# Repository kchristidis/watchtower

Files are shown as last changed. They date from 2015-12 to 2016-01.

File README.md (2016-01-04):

# Watchtower

NC State ECE Senior Design Project, Fall 2015

## Description

Monitor the state of a building (temperature, luminosity, number of people) with easy-to-deploy Pi-based sensor boxes and an intuitive Web interface.

Allow others to access a sensor box you own using the dashboard.

Use the REST API to programmatically export sensor data, and build applications on top of **Watchtower**.

[Video presentation](https://www.youtube.com/watch?v=rJIvThQTJWE) of the project on Design Day: 24m01s to 25m02s

## Contents

  - Source code for the Web interface
  - Schematics for the Pi PCB
  - Scripts for the Pi
  - Screenshots
  - Documentation

## Credits

Coded by:
  - Andrew Kofink <ajkofink@ncsu.edu>
  - Spencer Hitchins <jshitchi@ncsu.edu>
  - Scott Whalen <swwhalen@ncsu.edu>

Mentored by:
  - Kostas Christidis <kchrist@ncsu.edu>
  - Michael Devetsikiotis <mdevets@ncsu.edu>

Sponsored by: 
  - IBM

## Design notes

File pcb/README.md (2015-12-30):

  - `sensor_pcb.brd` is the board file for EagleCAD for the PCB in our project that connects to the Raspberry Pi
  - `sensor_pcb.sch` is the schematic file for EagleCAD for the PCB in our project that connects to the Raspberry Pi
  - `gerber-files` contains all the files needed when sending the PCB to a manufacturer

When soldering the sensors on there is a label next to each set of wholes on the top side saying which sensor goes where, and on the under side shows a `V` for where the positive voltage pin should go. For a more simple explanation of how to orient the sensors, when looking at the side with the name labels and with the double row of pin wholes on the top you want each sensor to be mostly to the right of the pin wholes that go with that sensor.

Scott Whalen
swwhalen@ncsu.edu

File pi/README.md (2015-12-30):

# scm-scripts

## Author:
Spencer Hitchins (jshitchi@ncsu.edu)

## Python Version: 
python-2.7.9

## System Dependencies:
Adafruit BMP085 Python Library
pip
postgresql
python-opencv
RPi.GPIO
virtualenv

## Getting Started:

#### Enter scm-scripts directory:
cd scm-scripts

#### Create and activate virtualenv:
virtualenv venv
source venv/bin/activate

#### Install dependencies:
pip install -r requirements.pip

#### Create secrets file:
touch secrets.py

#### Copy example config file to config file location (descriptions of how to change this file are included in the example file):
cp conf/sensors.ini.example conf/sensors.ini

#### Run people counting script in background:
python people_counter.py &

#### Run data capture script
python capture_data.py

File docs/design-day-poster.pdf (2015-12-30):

## Complete System Overview

## Counting People with a Camera

# Team 4: Tracking and Predicting the State of a Building

A

Custom PCB

Temperature
Sensor

Luminosity
Sensor

Barometric
Pressure
Sensor

Number of
People

# Team Members: Scott Whalen, Andrew Kofink, Spencer Hitchins Sponsors & Mentors: IBM, Kostas Christidis, Prof. Michael Devetsikiotis

Web Application Logic
IBM’s Bluemix with 512MB RAM, 1 running process

Web Interface

Buildings and Sensor Modules Raspberry

Pi

Raspberry
Pi
Web Access

Database
PostgreSQL on IBM’s Compose with 1GB storage, auto-scalable IO

Sensor readings sent at
configurable frequency (30 min.)

Left
Quad

Right
Quad

## Requirements

- Web application
- Collects data from sensor modules (Raspberry Pi)
- Displays historical data
- Aesthetically pleasing
- Prediction for variables
- Tracks variables
- Light
- Temperature
- Barometric Pressure
- Number of People (Motion)

## Problem Statement

To have an inexpensive electronic device that can track the state of a building. The data will be shown in a web app, and will also be used for predicting future states of a building.

## Conclusions

- OpenCV can effectively be used to count objects passing through the frame of a Pi camera.
- Typical infrared emitter/detector diodes have a severely limited range of operation (5-25cm).
- The luminosity sensor was significantly affected by the clear plastic case. Holes were drilled in the case to accommodate this issue.

The camera
module shown
above is used in
conjunction with
custom image
processing
software to count
the number of
people travelling
in a given
direction.

## Web Application

- assigns each sensor module a unique serial number, which is displayed on a sticker on the module
- graphs historical data as well as future predictions up to 1 week into the future
- enforces user-defined access privileges for sensor data

## Sensor Module

- Raspberry Pi B+ with Custom PCB
- The device boots when the user connects power via a provided AC to 5V DC converter
- Data is sent as soon as the device boots
- Data is sent from all four sensors once every 30 minutes

## Sensors

Barometric pressure | Temperature

Luminosity

These three sensors communicate via I

2C

Number of
people

## Testing and Demo

- We installed 3 sensor modules in Troxler lab for 2 weeks prior to design day for historical data.

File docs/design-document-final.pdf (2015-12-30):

# Team 4

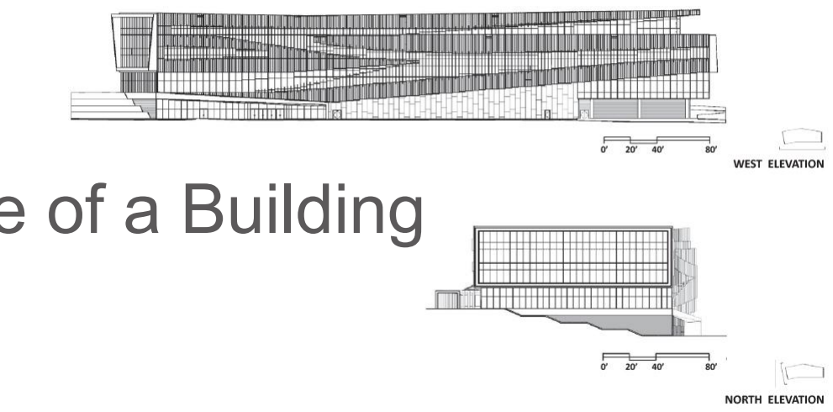
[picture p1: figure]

# Tracking and Predicting the State of a Building

## Faculty Mentors Kostas Christidis Bobby Compton

Spencer Hitchins | Sensor Control Module Manager, UI Design Specialist, Sponsor Contact
Andrew Kofink | Web Application Manager, Software Specialist, Documentation Specialist
Scott Whalen | PCB Manager, Project Leader, Hardware Specialist

# Introduction

# - IBM is sponsoring this internet of things (IoT) project - Track multiple sensor variables about a building - Display historic data and make forecasts via a web app - Motivations: - Inexpensive electronics - Many devices in the IoT - Need a common data interface

# Project Requirements

# - IoT devices push data to DB - web application displays data - system is easy to use - IBM technology is showcased - multiple sensor data per module

# Change Summary

# - no more detailed prediction algorithms - web app overhaul - switched database - shifted focus from extensibility to ease of use - sound sensor dropped - enclosure added

# Project Architecture

# Raspberry Pi

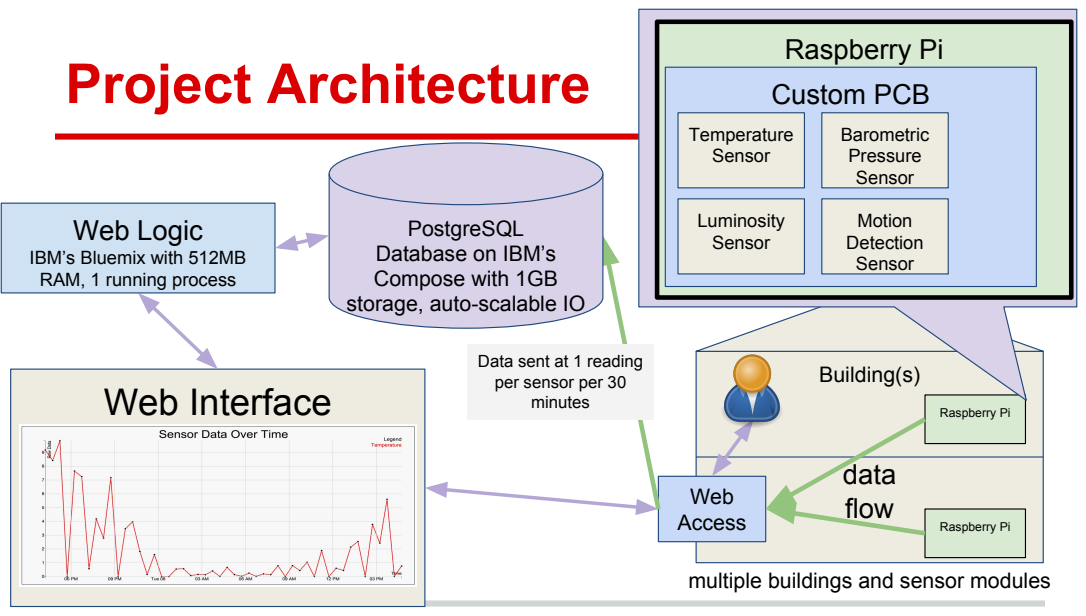
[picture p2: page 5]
Building(s); Web Interface; Raspberry Pi; Web Access; Custom PCB; Luminosity Sensor; Motion Detection Sensor; data flow

Temperature | Barometric
Sensor | Pressure Sensor

Web Logic
IBM’s Bluemix with 512MB
RAM, 1 running process

PostgreSQL
Database on IBM’s
Compose with 1GB
storage, auto-scalable IO

Data sent at 1 reading
per sensor per 30
minutes

multiple buildings and sensor modules

# Raspberry Pi

# - 5.2 power supply - 16GB Sandisk microSD card - Kootek wifi dongle

# PCB

# - 2 layer board - 56mm x 58mm(2.2” x 2.3”) dimensions - daughter board for Raspberry Pi - .016” routes

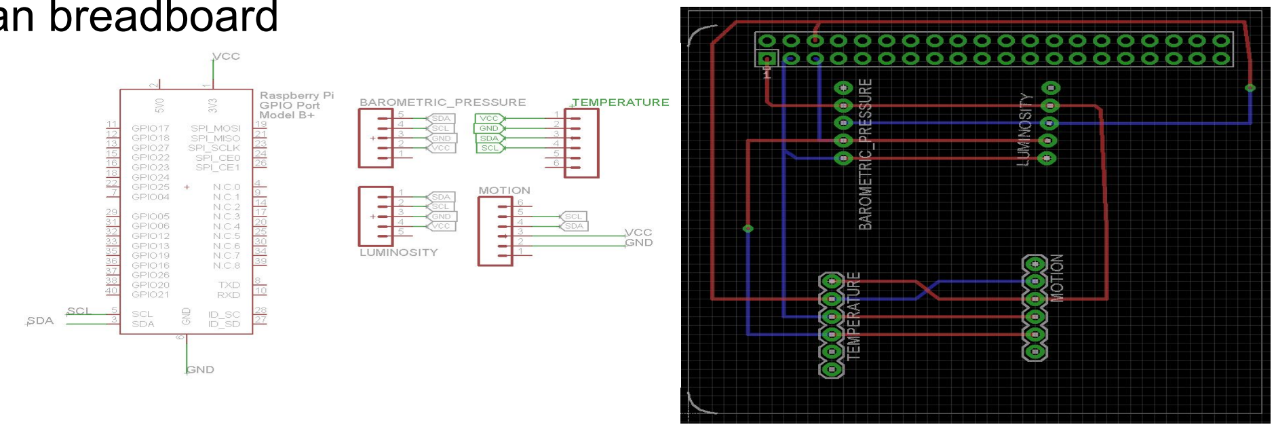
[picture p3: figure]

# - neater than breadboard

# Sensors

# - have light, temperature, barometric pressure, motion

- I2C

# - 3.3v power supply - sparkfun - easy breakout board

# Light

# - range: of 0.1 - 40k+ Lux - troxler - ~380 Lux - .6” x .6” dimensions - URL: https://www.sparkfun.com/products/12055

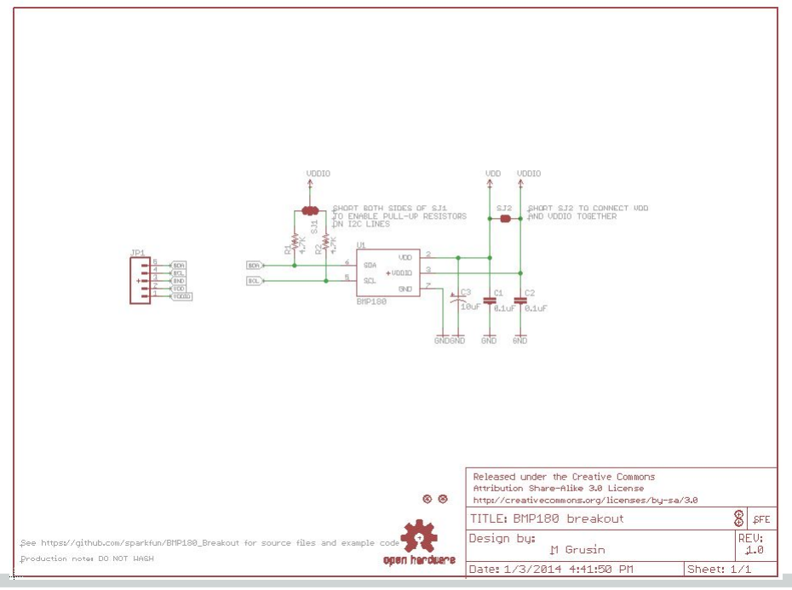
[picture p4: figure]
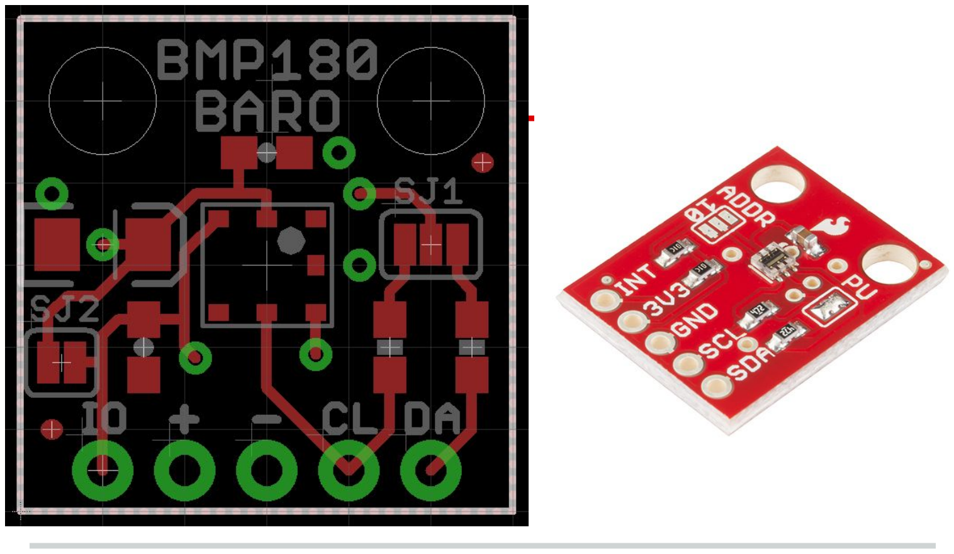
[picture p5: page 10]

# Temperature

# - .0625° C resolution, .5° C accuracy - range: -25° C(-13° F) - 85° C(185° F) - .6” x .6” dimensions - URL: https://www.sparkfun.com/products/11931

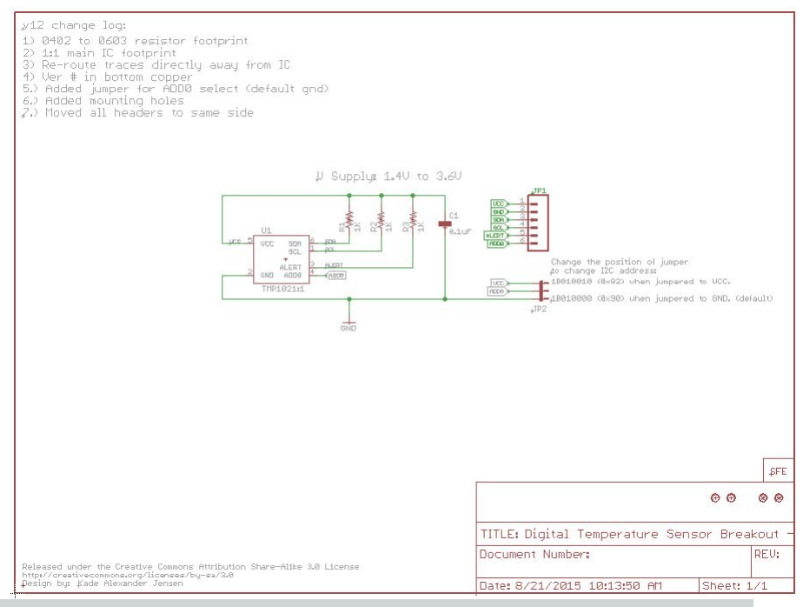
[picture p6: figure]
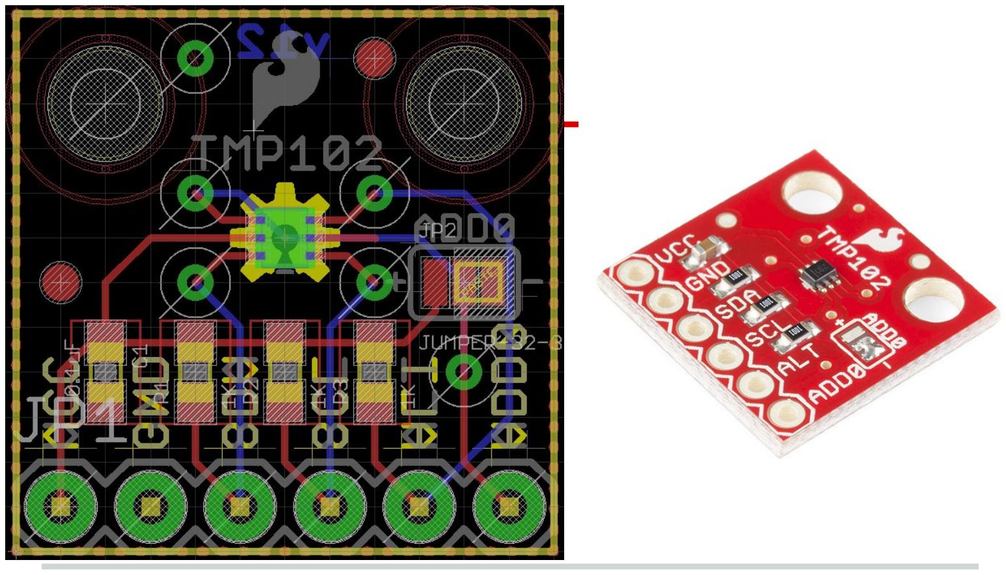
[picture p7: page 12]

# Barometric Pressure

# - .02 hPa accuracy - range: 300-1100 hPa - standard atmosphere - 1013.25 hPa - .6” x .8” dimensions

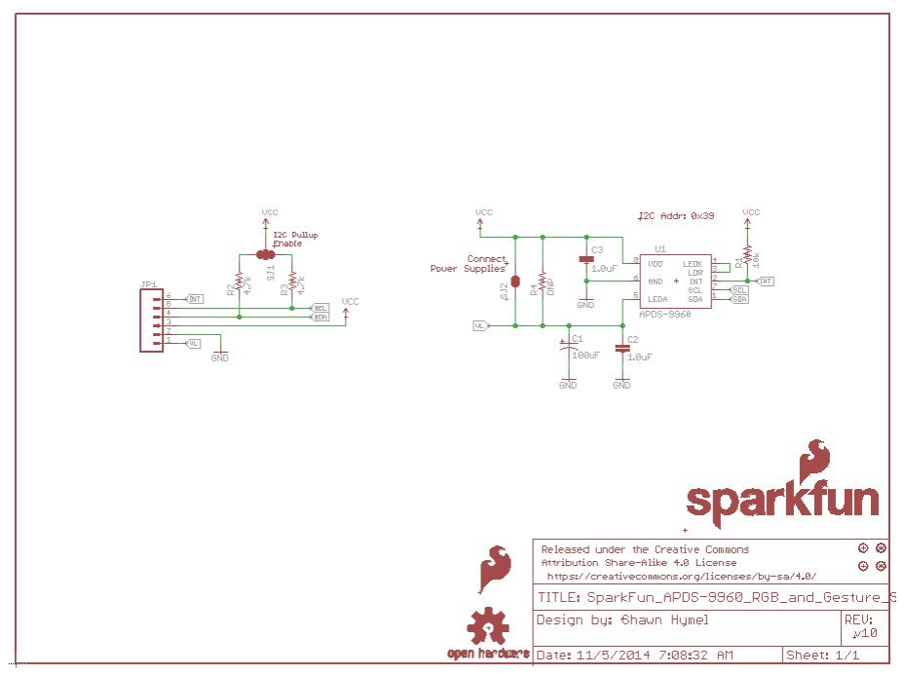
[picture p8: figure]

# - URL: https://www.sparkfun.com/products/11824

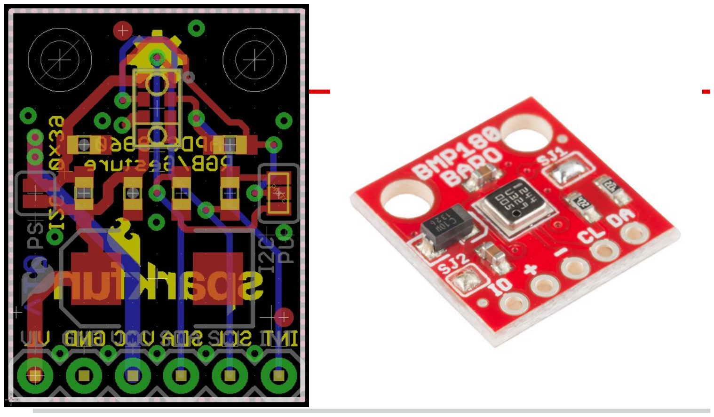
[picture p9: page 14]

# Motion

# - 4”-8” detection range - gesture detection, proximity sensing - .6” x .75” dimensions - URL: https://www.sparkfun.com/products/12787

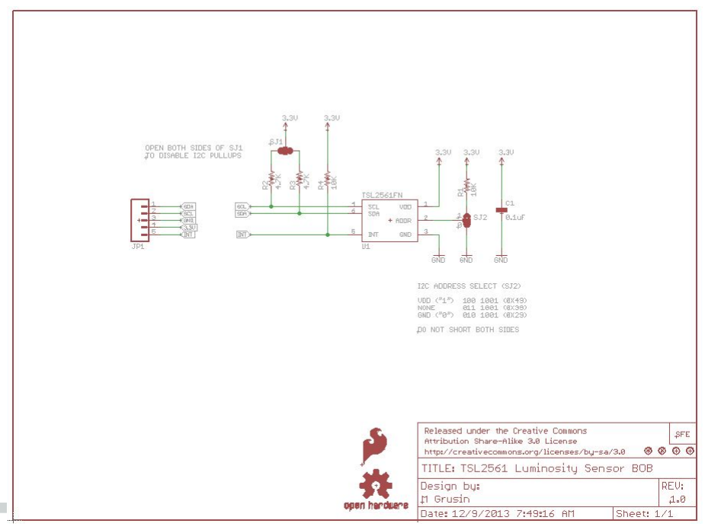
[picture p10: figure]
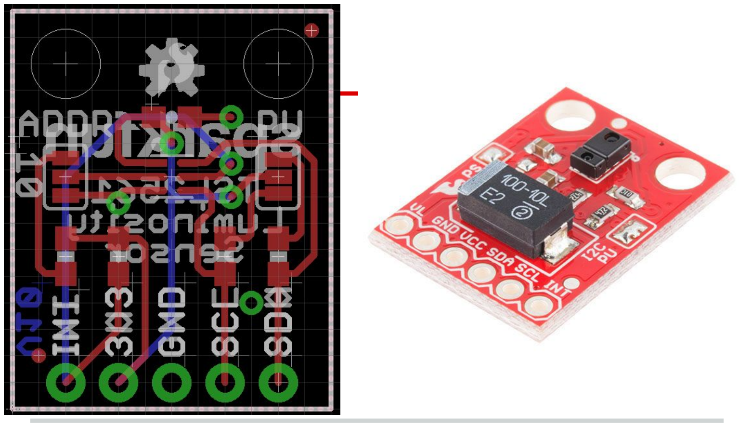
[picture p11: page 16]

# Enclosure for PCB and Raspberry Pi

- http://www.amazon.com/dp/B00MQLB1N6/

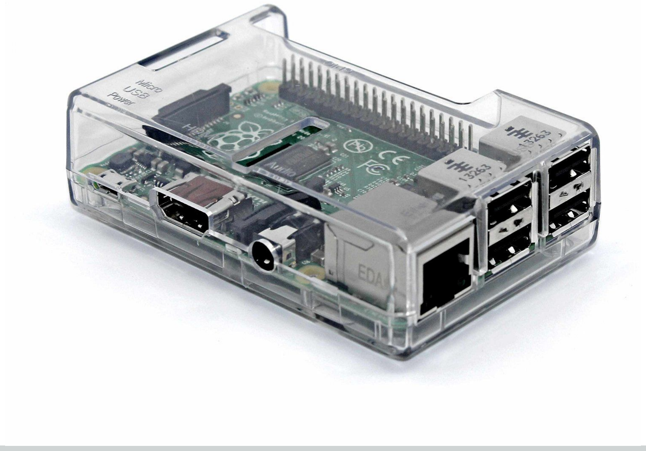
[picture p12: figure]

# Power Budget

# - Raspberry Pi takes up to 50mA per pin - temperature sensor uses up to 10µA - BMP sensor uses up to 5µA - motion sensor uses up to 250µA - luminostiy sensor up to uses .6mA

- total = 10µA + 5µA + 250µA + .6mA = .

# 865mA power budget (well below 50mA)

# Hardware Testing

# - solder on headers to PCB

# - easy connect/disconnect for sensors and from Raspberry Pi

# - check connections are good with PCB

# - make sure Raspberry Pi can read from sensors and get valid data

# - use multimeter/oscilloscope to debug issues

# - have vias and other holes that can be used as test points

# Hardware Testing (cont)

# - double check that solder points aren’t soldered together by accident

# Design Challenges

# - sound sensor - Raspberry Pi vs. Beaglebone Black - why not 3D-printed enclosure

# Raspberry Pi Software Architecture

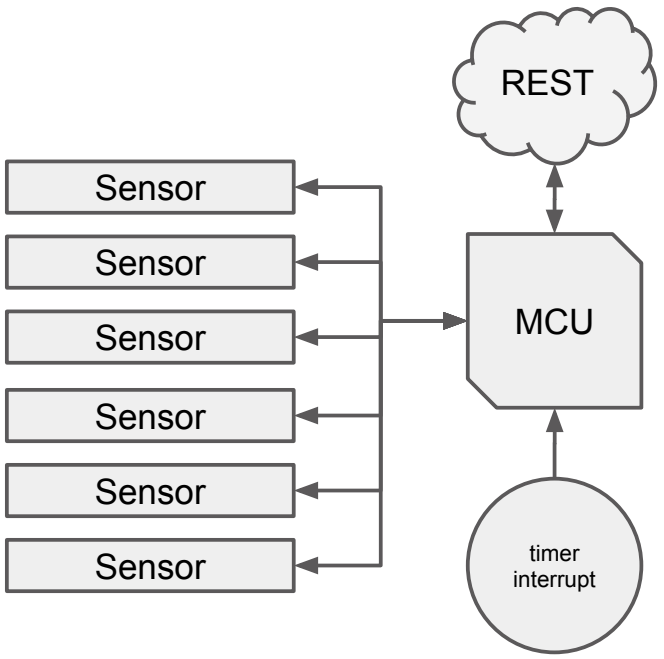
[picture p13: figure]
MCU; timer Sensor; interrupt; Sensor; REST

# Sensor Control Module

# - Consists of Raspberry Pi and daughter board with sensors - Preloaded with unique module ID and IDs for each sensor - Ships with microSD card preloaded with golden image

# - Software and packages pre-installed

# Sensor Software Requirements

# - Raspbian - Python v2.7.9 - Pip v1.5.6 - Python Packages

# - psycopg2 v2.6.1 - smbus-cffi v0.5.1

# - Git v1.7.10

# Sensor Software

# - Bash Scripts

# - Run on system startup - Activate Python scripts

# - Python Scripts

# - Communicate with sensors - Push data to web application

# - Python Configuration Files

# - Provide information about sensors

# Sensor Software Test Plan

# - Unit tests for functions using PyUnit - Test integration with database

# - Manually ensure data actually sent to database

# - Test integration with PCB

# - Ensure PCB connections correctly allow I2C communication with each sensor

# Shipping

# - Before

# - Unique module and sensor IDs loaded in database - Unit testing to ensure module integrity

# - After

# - Ships with instructions and sticker with unique ID ■ Plug in Pi ■ Visit URL in instructions ■ Register with unique ID on sticker

# - Data immediately begins pushing to DB

# Sensor Software Timeline

Item Description | Expected Completion
Integrate temperature sensor with database | 2015-09-07
Integrate luminosity sensor with database | 2015-09-16
Integrate barometric pressure sensor with database | 2015-09-30
Test PCB integration with temperature sensor, luminosity sensor, and barometric pressure sensor | 2015-10-05 (Alpha Demo)
Test PCB integration with proximity sensor | 2015-10-14
Integrate proximity sensor with database | 2015-10-21
Complete registration workflow for module | 2015-11-04 (Beta Demo)
Design Day, Version 1.0.0 locked | 2015-12-01

# Design Challenges

# - Ease of use vs. Extensibility - Differences in sensors

# - Data addresses - Control signals - Power signals

# - Data format

# MVC Software Architecture

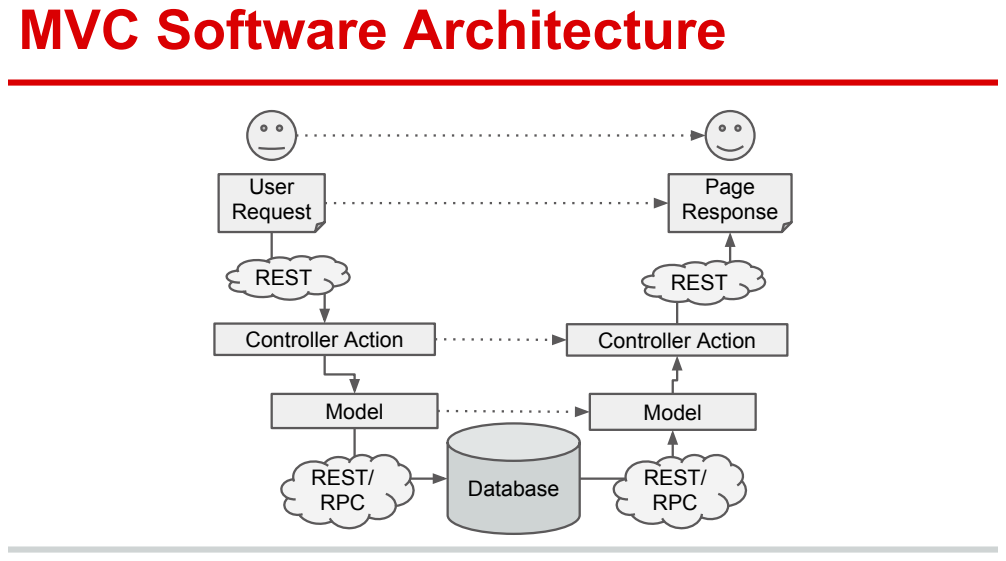
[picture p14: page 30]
Controller Action; User Request; Model; Database; Page Response; REST/ RPC; REST

# Web Application DB Schema

dashboards
integer "id"
integer "user_id"
text | "config"
string | "name"
datetime "created_at"
datetime "updated_at" | data_points
integer "id"
integer "sensor_id"
float "data"
datetime “timestamp”
datetime "created_at"
datetime "updated_at"

sensor_accesses
integer "id"
integer "sensor_id"
integer "user_id"
datetime "created_at"
datetime "updated_at"

sensor_module_accesses
integer "id"
integer "sensor_module_id" integer "user_id"
datetime "created_at"
datetime "updated_at" sensors integer "id"
string "name"
integer "sensor_module_id"
datetime "created_at"
datetime "updated_at"

sensor_modules
integer "id"
string | "name"
string | "location"
integer "user_id"
datetime "created_at"
datetime "updated_at"

users
integer "id"
string "username"
string "password_digest"

# Web Application Routes

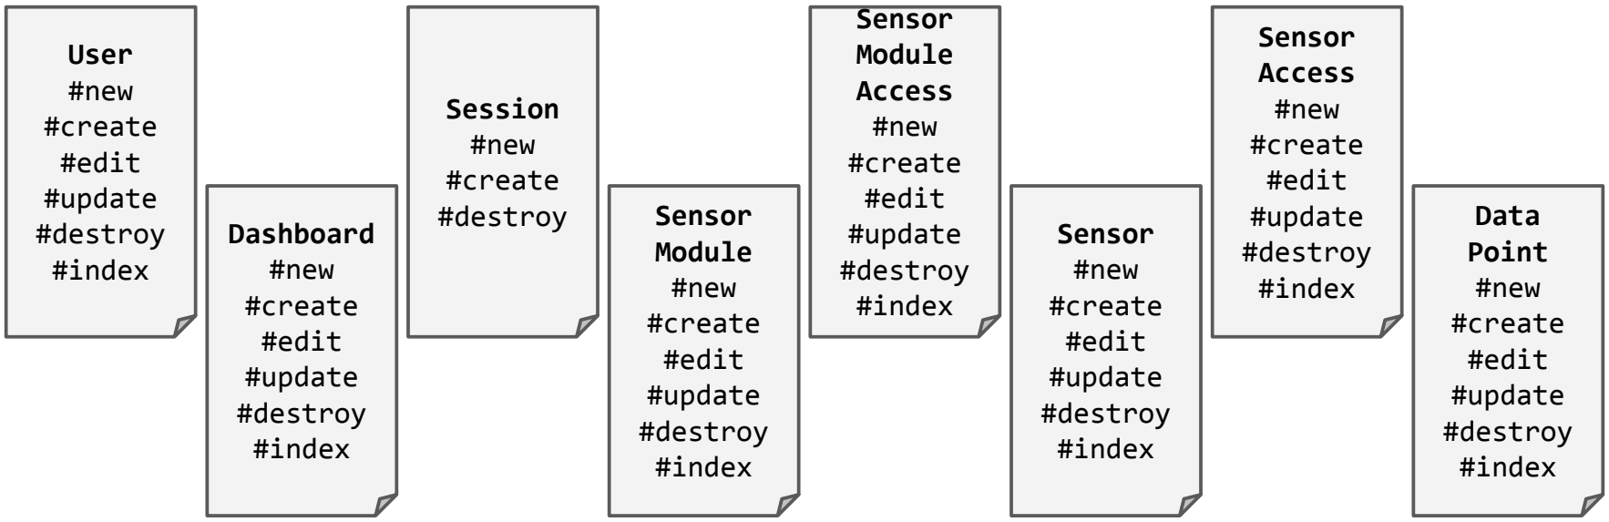
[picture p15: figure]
User #new #create #edit #update #destroy #index; Session #new #create; #destroy; Sensor; Module #new #create #edit #update #destroy #index; Sensor #new #create #edit #update #destroy #index; Sensor Access #new #create #edit #update #destroy #index; Sensor Module Access #new #create #edit #update #destroy #index; Dashboard #new #create #edit #update #destroy #index; Data Point #new #create #edit #update #destroy #index

# Web UI Libraries

# - Bootstrap v.3.3.5 - D3.js v.3.5.6 - HAML v.4.0.6 - Font Awesome v.4.4.0 - SASS v.3.2.19 - jQuery v.2.1.4 - Uglifier v.2.7.0 - Turbolinks v.2.5.3

# Web Management Libraries/Tools

# - Bundler v.1.10.6 - Rake v.10.4.2 - Cloud Foundry v.6.12.2 - Pry v.0.10.1 - Git v.2.2.2

# Web Testing/Analysis Libraries

# - Capybara v.2.4.4 - RSpec v.3.1.0 - Rspec Mocks v. 3.1.3 - SimpleCov v.0.9.1 - Guard v.2.11.1

# Web Backend Libraries

# - Bcrypt v.3.1.9 - ActiveRecord v.4.0.13 - ActiveModel v.4.0.13 - AREL v.4.0.2 - PostgreSQL v.9.4.4 - Rack v.1.5.2 - Unicorn v.4.9.0

# Resource Hosting

# - Bluemix by IBM (Ruby on Rails) - Compose by IBM (PostgreSQL) - Users must purchase internet service - Users must have an 802.11abg 2.5Ghz AP

# D3 Flowchart (FC) - simple_plot()

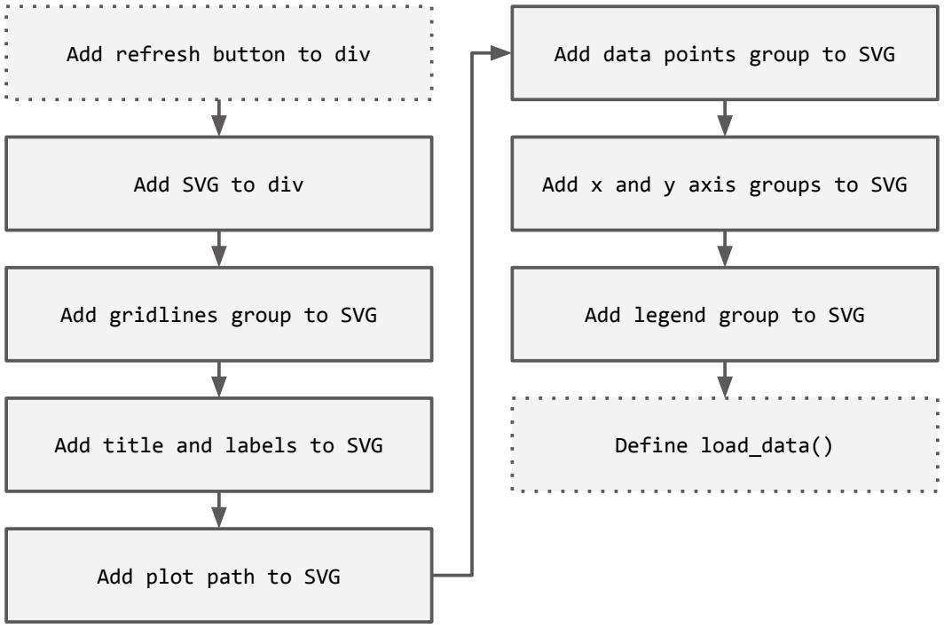
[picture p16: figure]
Add refresh button to div; Add SVG to div; Add gridlines group to SVG; Add title and labels to SVG; Add plot path to SVG; Add data points group to SVG; Add x and y axis groups to SVG; Add legend group to SVG; Define load_data()

# D3 FC - load_data()

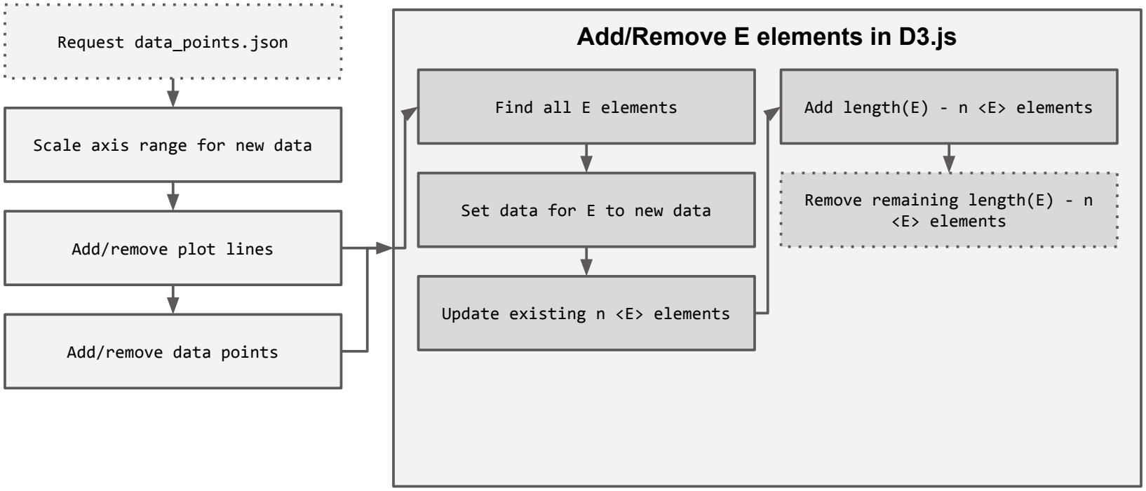
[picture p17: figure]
Request data_points.json; Scale axis range for new data; Add/remove plot lines; Add/remove data points; Add/Remove E elements in D3.js; Find all E elements; Set data for E to new data; Update existing n <E> elements; Add length(E) - n <E> elements; Remove remaining length(E) - n <E> elements

# Control Module Identification FC

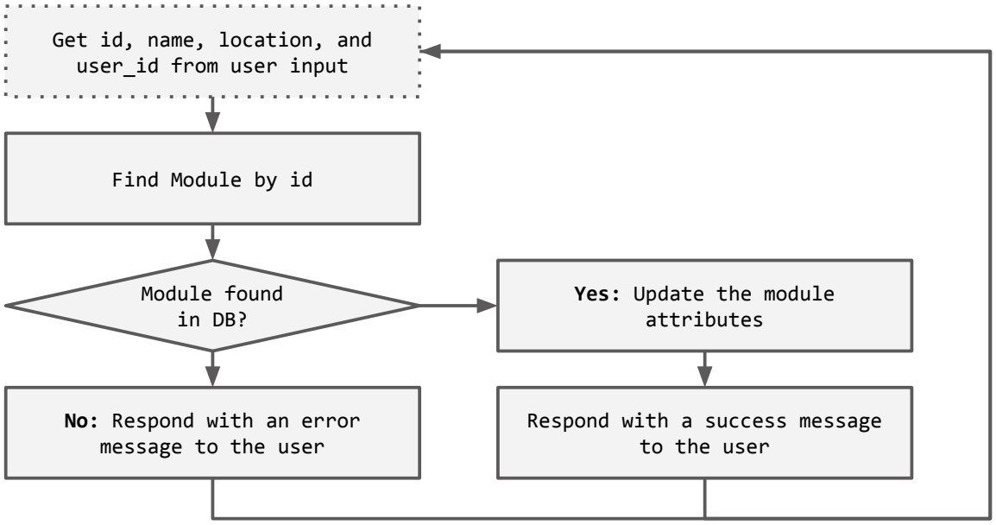
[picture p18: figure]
Get id, name, location, and user_id from user input; Find Module by id; Module found in DB?; No: Respond with an error message to the user; Yes: Update the module attributes; Respond with a success message to the user

# Web Application Test Plan

# - Unit tests written for all models using RSpec

- data_point, sensor_access, sensor_module_access,

# dashboard, sensor, sensor_module, user

# - Integration tests written for all controllers/views using RSpec Mocks

- data_points, sensor_accesses, sensor_module_accesses,

# dashboards, sensors, sensor_modules, users

# - Acceptance Test list for manual exercising requirements

# Black Box Acceptance Tests

- Users can create a user account - Users can log in - Users can add sensor modules - Users can edit sensor metadata - Users can delete data points - Users can grant/revoke access to their sensors - Users can grant/revoke access to their control modules - Users can create new dashboards - Users can edit and delete their dashboards

# Web Application Timeline

Item Description | Expected Completion
Adding strict authorization | 2015-09-16
Adding web encryption | 2015-09-23
Adding an administrative system | 2015-09-30
Allowing users to switch sensors shown on the dashboard plot | 2015-10-05
Allowing users to add multiple plots per graph | 2015-10-05 (Alpha Demo)
Allow displaying of historical data (user-specified date range) | 2015-10-14
Allowing users to save/edit the dashboard configuration | 2015-10-14
Allowing users to add multiple graphs on the dashboard | 2015-11-04 (Beta Demo)
Adding basic prediction mechanism | 2015-11-11
Design Day, Version 1.0.0 locked | 2015-12-01

# Manufacture/Running Cost

- | Luminosity: https://www.sparkfun.com/products/12055 | $5.95
- | Temperature: https://www.sparkfun.com/products/11931 | - $5.95
- | Barometric Pressure: | https://www.sparkfun.com/products/11824 | - $9.95
- | Motion: https://www.sparkfun.com/products/12787 | - $14.95

# - Raspberry Pi B+: ~$30.00 - PCB: ~$30.00 - MicroSD card: $10 - wifi dongle: $8 - Bluemix Hosting (1 instance at 512MB RAM) - free (scalable) - Compose PostgreSQL Hosting - $17.50/month minimum (scalable)

# Total: ~$114.80 + $17.50 / month

# Alpha Demo (2015-10-05)

# - 3 sensors - Authorization on the web application - TLS on the web application - Multiple plots per graph

# Beta Demo (2015-11-04)

# - All sensors - PCB mounted to control module - Control module housed in the enclosure - Add UUID sticker for the Pi - Multiple graphs on a dashboard - Save/edit dashboard configuration - Complete user unboxing web workflow

# Final Design Day Demo (2015-12-04)

# - Example sensor control module - Web application demo - Data from three modules tracking Troxler lab for the week prior to design day

# - One by each door - One near a window

# Demo

# http://tpsb.mybluemix.net

# Q & A - IBM Team 4

# Team Members: Scott Whalen Spencer Hitchins Andrew Kofink

# Bill of Materials

- | Luminosity: https://www.sparkfun.com/products/12055 | $5.95
- Datasheet: http://cdn.sparkfun.com/datasheets/Sensors/LightImaging/TSL2561.pdf
- Temperature: https://www.sparkfun.com/products/11931 - $5.95
- Datasheet: http://www.sparkfun.com/datasheets/Sensors/Temperature/tmp102.pdf
- | Barometric Pressure: https://www.sparkfun.com/products/11824 | - $9.95
- Datasheet: http://cdn.sparkfun.com/datasheets/Sensors/Pressure/BMP180.pdf
- | Pi Camera: http://www.adafruit.com/products/1367?gclid=CNW1zuesickCFYc8gQod3dAKOQ | - $29.95
- Datasheet: http://www.element14.com/community/servlet/JiveServlet/downloadBody/54413-102-1-273177/Unofficial%20guide%20to%20getting%20up%20and%20running%20with%20the%20Raspberr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 (http://www.element14.com/community/servlet/JiveServlet/downloadBody/54413-102-1-273177/Unofficial%20guide%20to%20getting%20up%20and%20running%20with%20the%20R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)
- Raspberry Pi B+: http://www.amazon.com/Raspberry-Pi-Model-512MB-Computer/dp/B00LPESRUK/ref=sr_1_3?
ie=UTF8&qid=1449783772&sr=8-3&keywords=raspberry+pi+b%2B (http://www.amazon.com/Raspberry-Pi-Model-512MB-Computer/dp/B00LPESRUK) | - $30.00
- | PCB: http://www.4pcb.com/pcb-student-discount.html | - $33.00
- MicroSD card: http://www.amazon.com/SanDisk-microSDHC-Standard-Packaging-SDSQUNC-032G-GN6MA/dp/B010Q57T02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 (http://www.amazon.com/SanDisk-microSDHC-Standard-Packaging-SDSQUNC-032G-GN6MA/dp/B010Q57T02?s=pc) - $10.95
- WiFi dongle: http://www.amazon.com/Edimax-EW-7811Un-150Mbps-Raspberry-Supports/dp/B003MTTJOY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 (http://www.amazon.com/Edimax-EW-7811Un-150Mbps-Raspberry-Supports/dp/B003MTTJOY?s=pc) - $9.99
- Raspberry Pi B+ case: http://www.amazon.com/Premium-Clear-Case-Raspberry-Model/dp/B00MQLB1N6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 (http://www.amazon.com/Premium-Clear-Case-Raspberry-Model/dp/B00MQLB1N6) - $8.92
- Bluemix Hosting (1 instance at 512MB RAM) - free (scalable)
- Compose PostgreSQL Hosting - $17.50/month minimum (scalable)

Total: $144.66 + $17.50 / month

# Final Prototype Cost

- 4x Sensor Modules ($144.66)
- 2x Extension Cords ($15.99)
- 4x Sound Detectors ($10.95, unused)
- Datasheet: http://cdn.sparkfun.com/datasheets/Sensors/Sound/LMV324.pdf
- 2x Long Range IR sensor ($14.95, unused)
- Datasheet: https://www.sparkfun.com/datasheets/Sensors/Infrared/gp2y0a02yk_e.pdf
- Adafruit ADS1015 12-Bit ADC ($9.95, unused)
- Datasheet: http://adafruit.com/datasheets/ads1015.pdf

Total: $609.26

Not all items had to be purchased because the department owned them already.

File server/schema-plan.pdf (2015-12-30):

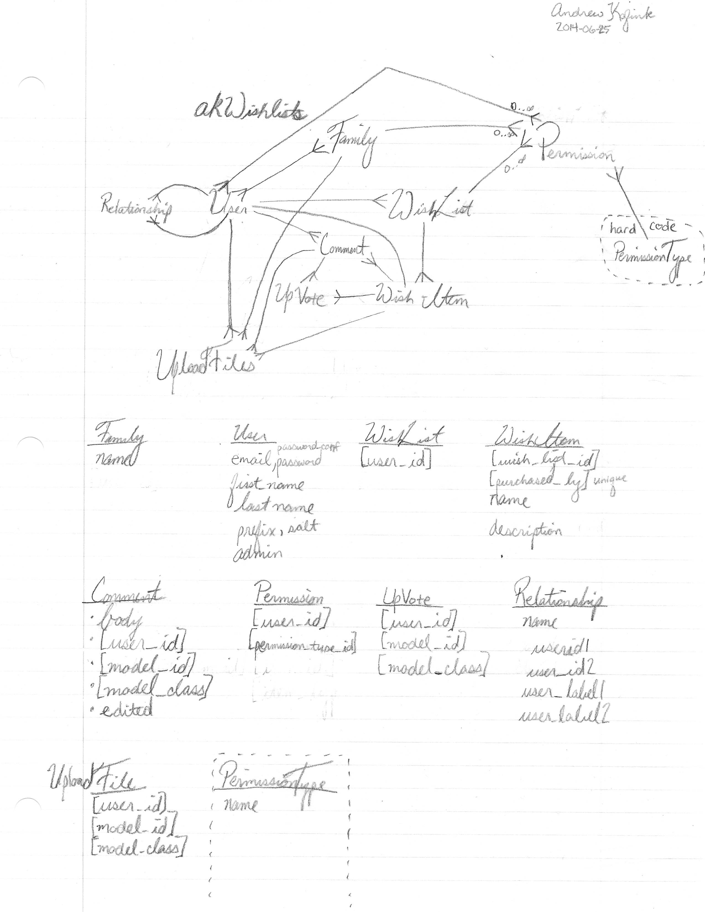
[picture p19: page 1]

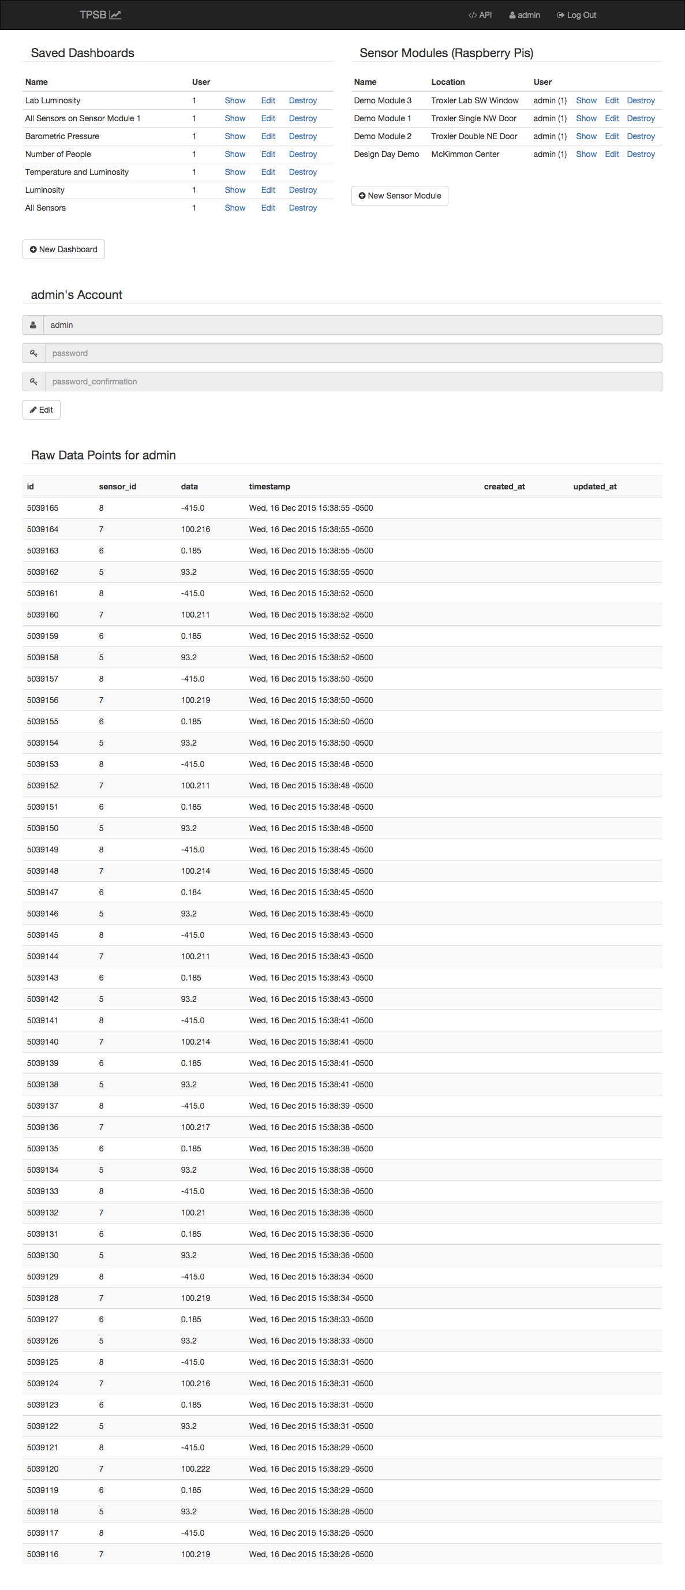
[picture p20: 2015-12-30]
screenshots/dashboard.png

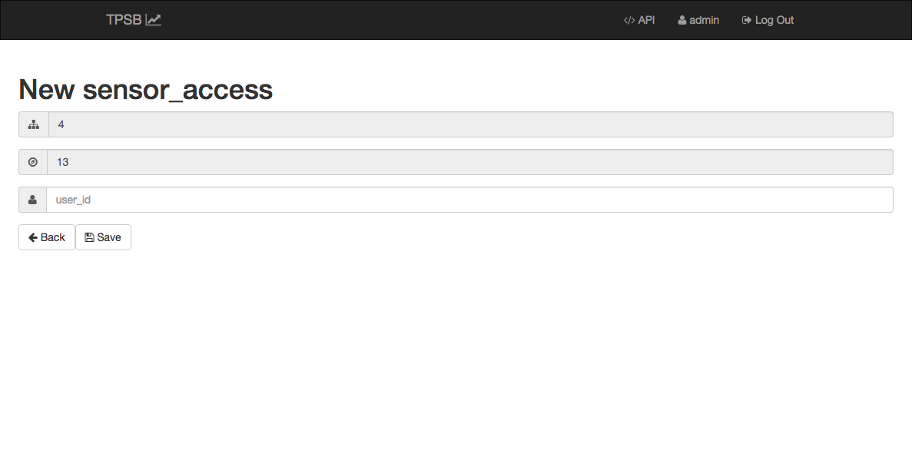
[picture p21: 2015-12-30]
screenshots/sensor-access.png

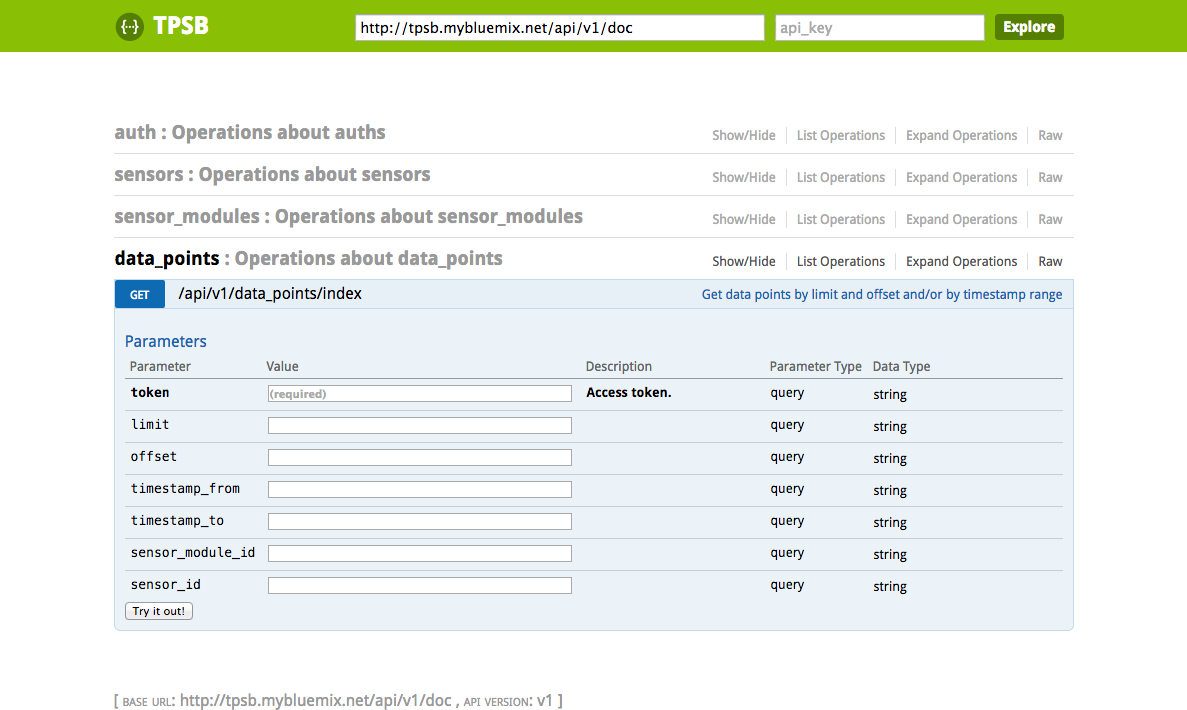
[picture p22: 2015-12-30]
screenshots/api.png

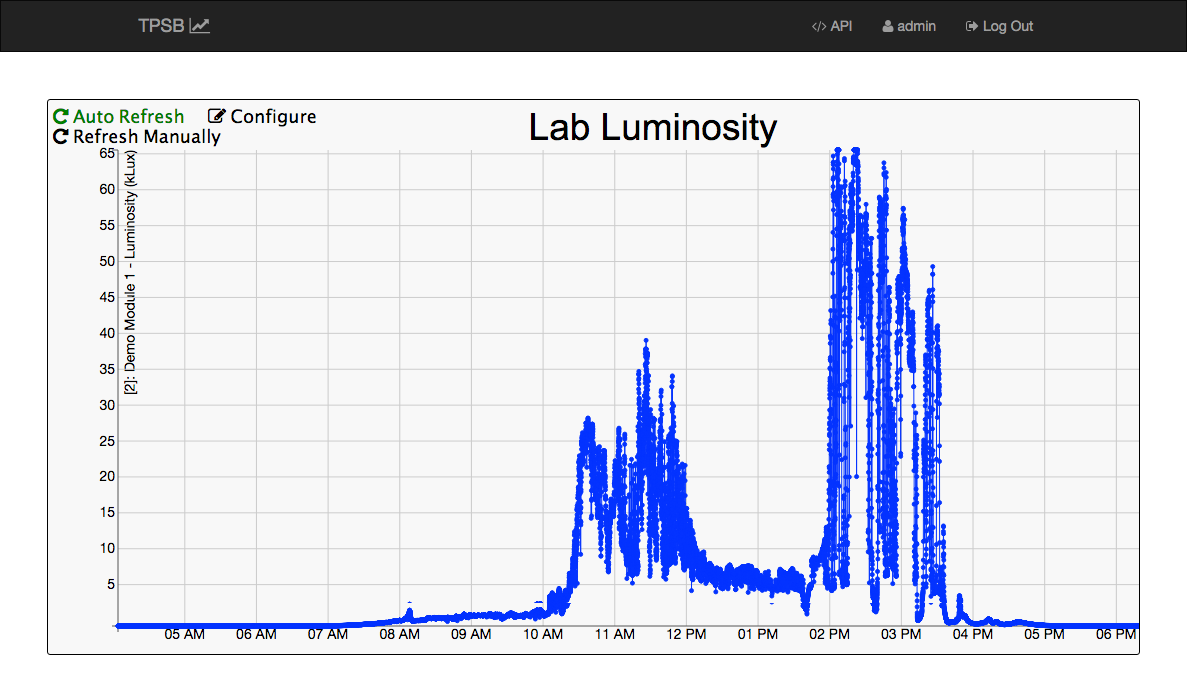
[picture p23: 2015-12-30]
screenshots/graph.png

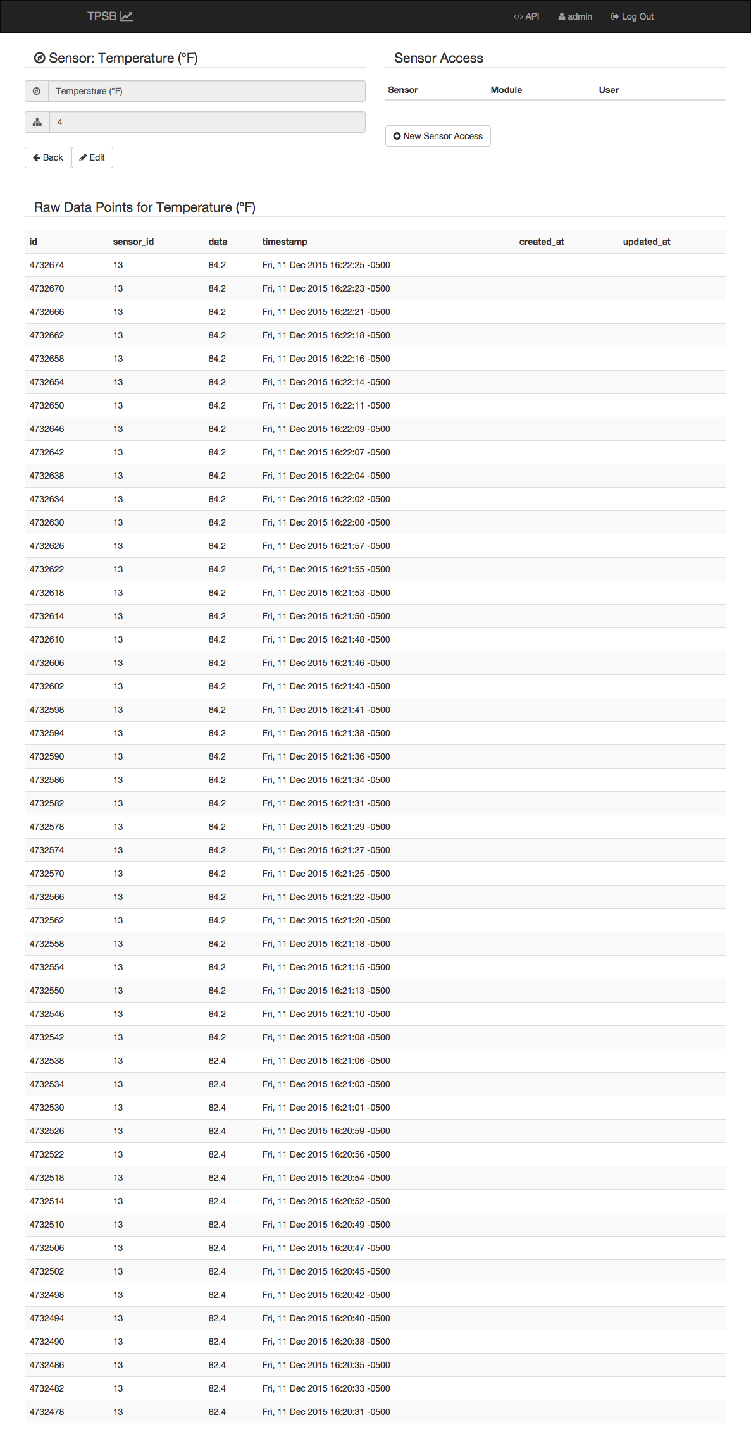
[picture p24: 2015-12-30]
screenshots/sensor.png

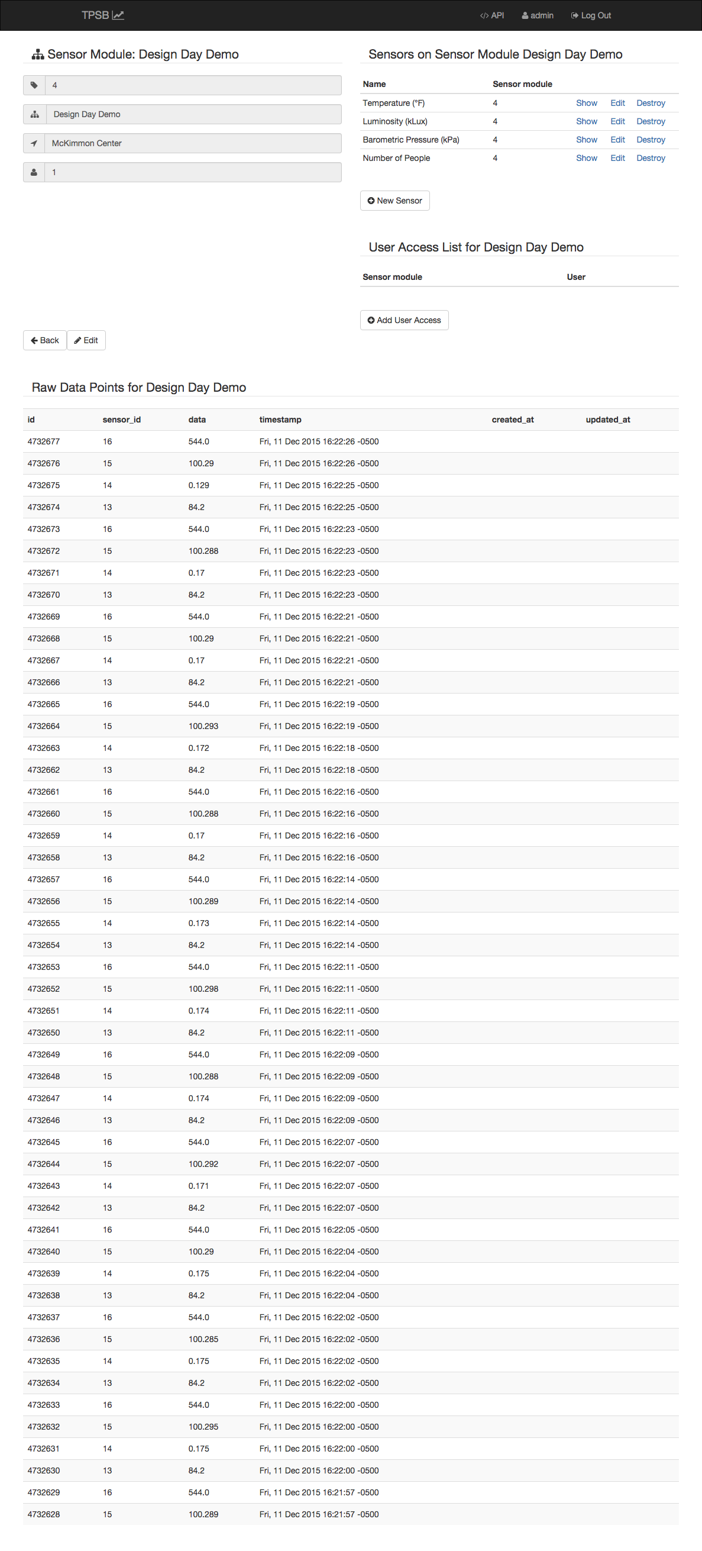
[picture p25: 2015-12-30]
screenshots/module.png

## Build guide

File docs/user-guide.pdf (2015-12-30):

# User Guide

Congratulations on your purchase! You are soon to be a part of the Internet of Things (IoT)! Follow this guide to set up quickly and looking at your data.

In the box:
- 1x Sensor Module
- 1x Power Supply
- 1x adhesive velcro
1. Unpackage the sensor module.
2. Plug the MicroUSB side of the power adapter into the sensor module and the other side into a wall outlet. The sensor module will turn on immediately.
a. Stand out of the camera’s field of view as the sensor module starts up.
3. On your sensor module, locate the ID number label. This is a numeric value.
4. Mount the sensor module in a doorway using the provided velcro if you want to count the number of people in that room.
5. Plug in the sensor module
a. If you intend to count the number of people then make sure not to stand in front of it until you see the light on the camera go on.
6. Make an account at https://tpsb.mybluemix.net, and log in.
7. Add a new sensor module by clicking the New Sensor Module button.
a. You may name your sensor module whatever you like, such as the location of the module, in order to distinguish between modules.
8. Create a new dashboard by clicking on the New Dashboard button.
a. You may name your dashboard whatever you would like. For example you could name the dashboard Light if you want it to show just your Luminosity sensor.
9. Now visit your new dashboard, and add sensors to the graph by first clicking the Configure button and then checking the checkboxes next to each sensor you wish to visualize.
a. You may change the color of each plot by clicking the color picker box.
10. Make as many dashboards as you wish to group whichever sensors on a single graph as you want. You may configure the autorefresh rate, manually refresh the plot, add time bounds, and also limit the maximum number of data points shown on the graph.
11. You may also change permissions for the sensors to allow other users to view your sensors’ data.

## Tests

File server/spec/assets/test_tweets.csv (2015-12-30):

tweet_id | text | date | author | author_id
549975090298109952 | RT @appleinsider: Apple's latest Mac Pro continues to cause problems for professional users http://t.co/uuOuhZYhMX | Tue Dec 30 17:07:34 +0000 2014 | SilvioAccomando | 386181111
549975090801434624 | Great phone on @Snapdeal Amazing features in Ubislate 10 Ci thanks to Android OS. Good work! https://t.co/wiAe3laSMP … | Tue Dec 30 17:07:34 +0000 2014 | sinhh | 48923933
549975090851758080 | ¡He terminado la misión "Cartas con..." en Big Business Deluxe para Android! http://t.co/SVLZIQnH0I #Android #Androidgames #Gameinsight | Tue Dec 30 17:07:34 +0000 2014 | alesotsan | 2255518930
549975091212464128 | RT @Akamss: Health workers are on strike nationally. On what grounds is GEJ even re-contesting sef? Almajiri, uncompleted roads, fertilise… | Tue Dec 30 17:07:34 +0000 2014 | ameenah_y | 462534407
549975090977574914 | Emergency Care Technician Per Diem Warren, OH - Mercy Health - Warren, OH http://t.co/71Kl4Ry6Dc #FCRJobsMA | Tue Dec 30 17:07:34 +0000 2014 | FCRJobs | 599403741
549975091484704770 | RT @TheBucktList: Galaxy bath bomb from lush literally made my life omg 😍 http://t.co/k84Ho9QhKl | Tue Dec 30 17:07:34 +0000 2014 | perthez | 1404817861
549975091623112705 | syntax http://t.co/iLNhw8Rdty terabyte terabyte #amazon | Tue Dec 30 17:07:34 +0000 2014 | UvknL3boke | 2928076707
549975091526643713 | RT @FoneZoneSA: #عرض_اليوم كمية #جديدة #سامسونج_جالاكسي_ايدج 32Gb 5.6 إنش بـ3749 ريال #فقط الشحن #مجاني للطلب http://t.co/nrAr9JbAXS http:/… | Tue Dec 30 17:07:34 +0000 2014 | abdulazizzakrii | 475023265
549975091199885315 | Apple iPad 4th Generation 32GB, Wi-Fi, 9.7in - White via eBay http://t.co/Q2dYKMLzRq http://t.co/rsJCz6W2aQ | Tue Dec 30 17:07:34 +0000 2014 | ipadlistings | 2589081594
549975091665461248 | Medical alert: Root canal procedures threaten human health http://t.co/HGiK5Ztx7g | Tue Dec 30 17:07:34 +0000 2014 | paramofsunflowe | 21503693
549975091053076481 | Alhamed Allah Always believe in God, because there are some questions that even Google can’t answer. | Tue Dec 30 17:07:34 +0000 2014 | FatoohMoh | 1723823934
549975092101263360 | 広い道路のおかげで部族の人たちは喜んでいます。こんな建築があれば私の島はもっと素敵になります！http://t.co/N3jaRItzQ2 #android, #androidgames, #gameinsight | Tue Dec 30 17:07:34 +0000 2014 | yuassy__yukiko | 2948962910
549975092235890689 | RT @shauna_harrison: NYC be ready! I'm teaching a week of #fitness events w/a bad ass crew for @Wellthily! See who: http://t.co/mIze3TsLOC … | Tue Dec 30 17:07:34 +0000 2014 | RobinNYC | 13107852
549975091912900609 | “@DrScienceCat: I don't have time for this, Google. http://t.co/P7sA1gk5TB” @tatithegreat_ | Tue Dec 30 17:07:34 +0000 2014 | kellbell0814 | 239044739
549975092634337281 | If you follow me , ford be performing a great dream , I love you @NiallOfficial | Tue Dec 30 17:07:34 +0000 2014 | MelMacedo4 | 2950303083
549975092931743744 | ミャンマーのカフェでMBPとiPadとiPhoneとApple Watchをドヤ顔でシームレスに操作したら間違いなくヤンゴンジャーナルの一面を飾る(ヽ´ω`) | Tue Dec 30 17:07:34 +0000 2014 | sukerokugp02 | 372198426
549975092868812800 | RT @TheBucktList: Galaxy bath bomb from lush literally made my life omg 😍 http://t.co/k84Ho9QhKl | Tue Dec 30 17:07:34 +0000 2014 | Miguuuuueel_ | 608664592
549975092558852097 | dem tepat yha ati2 aja .G []RT @jhowmild: sodem lg didapur baca ginian.....()"jhokjisoo: pas lagi cuci tangan, tiba2 badan sebelah kanan din | Tue Dec 30 17:07:34 +0000 2014 | jhokjisoo | 2268267342
549975092911165440 | RT @classifiedfact: Always believe in God, because there are some questions that even Google can’t answer. | Tue Dec 30 17:07:34 +0000 2014 | SeunAruna | 1537772078
549975092210331648 | did they really search for 'how to sneak into a concert' on Google http://t.co/3VNbtafzcq | Tue Dec 30 17:07:34 +0000 2014 | izzface | 93559936
549975092944719872 | RT @NikeCIothing: Galaxy Roshes 🌌 http://t.co/DisTEIl0Oi | Tue Dec 30 17:07:34 +0000 2014 | daniellewoodz | 375206294
549975092781121536 | RT @ICCamilleri: #newyear #thriller #romance Week of Lies Revenge Thriller/Romance http://t.co/Gl7M75UF9a … http://t.co/UD19GbR2Tk … http:… | Tue Dec 30 17:07:34 +0000 2014 | kosikyou2 | 2583069936
549975093636386816 | @SIRlUISBLACK my best friend is having health issues rn | Tue Dec 30 17:07:35 +0000 2014 | braveshailene | 1122681308
549975093347368961 | RT @Deaka_Club: Comunicado oficial Deaka Club 2015 | https://t.co/ZsP1Q0Lyyu | Tue Dec 30 17:07:34 +0000 2014 | a_fuck_theworld | 1238485676
549975093527732224 | アイリスオーヤマ パイプハンガーシングル ブラック PE-E180アイリスオーヤマ(IRIS OHYAMA)(95)新品： ￥ 1,3237点の新品／中古品を見る: ￥ 810より (この商品の現在のランクに関する正式な情報... http://t.co/44mhPyhoQ9 | Tue Dec 30 17:07:34 +0000 2014 | Furniturewood | 1319883571
549975093837709312 | New Google Maps imagery shows 9 V-22 Osprey tilt-rotor aircraft at airbase in Kuwait http://t.co/auhrOJUKlQ via @theaviationist | Tue Dec 30 17:07:35 +0000 2014 | SciteCito | 779904919
549975093615820801 | #StevenDehler by #TiborGolob #Model #MaleModel #Fitness #Photoshoot #Photography #Hair #Sexy http://t.co/YIUpFbevOM | Tue Dec 30 17:07:35 +0000 2014 | Skippy9474 | 58420528
549975093611626497 | You Could Fill Up At The Pump With Apple Pay Starting Next Year http://t.co/yvSMk5kLS0 | Tue Dec 30 17:07:35 +0000 2014 | ArcherSutton | 2820167259
549975093917790209 | yarın olsunda çılgınlar gibi mandalina yesekk | Tue Dec 30 17:07:35 +0000 2014 | olmakboylebisey | 2561907323
549975094001664000 | Пару дней назад Google анонсировал проект The Physical Web («Материальный веб»), | Tue Dec 30 17:07:35 +0000 2014 | akeboyefekuv35 | 2850036567
549975093959352322 | oHaving fun playing #CSRRacing for Android, why not join me for FREE? http://t.co/RBX2uag6sd | Tue Dec 30 17:07:35 +0000 2014 | mellowdrama425 | 2946720744
549975094085582849 | RT @ManagersDiary: Focus on being a better Manager or Supervisor with "The 7 Deadly Sins of Leadership". Now available on Amazon: http://t.… | Tue Dec 30 17:07:35 +0000 2014 | GTaysever | 559008703
549975094182051841 | RT @NikeCIothing: Galaxy Roshes 🌌 http://t.co/DisTEIl0Oi | Tue Dec 30 17:07:35 +0000 2014 | MaaariaJoseM | 178540619
549975094567923713 | Pumped BMX 2: http://t.co/VGFRAnIfhn #pumpedbmx #bmx #bmxsupercross #MotoGP #itunes #appstore #MotoGPMotorLand #topapps #Apple #trending | Tue Dec 30 17:07:35 +0000 2014 | rtscam1410 | 2758049812

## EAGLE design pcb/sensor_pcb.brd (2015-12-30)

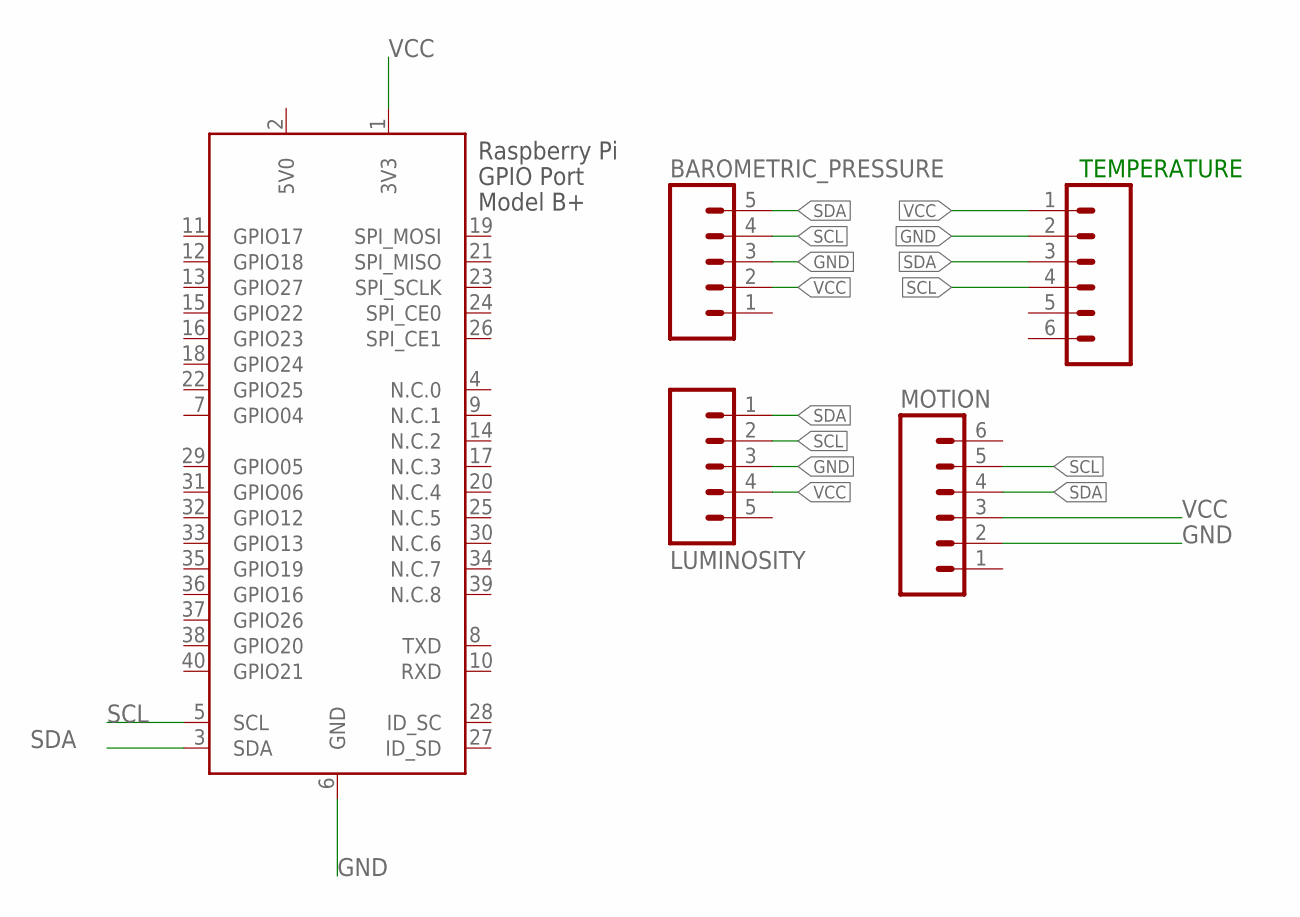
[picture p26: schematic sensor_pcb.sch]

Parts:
BAROMETRIC_PRESSURE: M05_ROUNDONLY_NOSILK; 1X05_ROUNDONLY_NOSILK
LUMINOSITY: M05_ROUNDONLY_NOSILK; 1X05_ROUNDONLY_NOSILK
MOTION: M06SIP; 1X06
TEMPERATURE: M06SIP; 1X06
X1: RASPI_BOARD_B+_E0; RASPI_BOARD_B+_EDGES_0DRILL

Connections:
5V0: X1.2 (5V0)
GND: BAROMETRIC_PRESSURE.3, LUMINOSITY.3, MOTION.2, TEMPERATURE.2, X1.6 (GND)
SCL: BAROMETRIC_PRESSURE.4, LUMINOSITY.2, MOTION.5, TEMPERATURE.4, X1.5 (SCL)
SDA: BAROMETRIC_PRESSURE.5, LUMINOSITY.1, MOTION.4, TEMPERATURE.3, X1.3 (SDA)
VCC: BAROMETRIC_PRESSURE.2, LUMINOSITY.4, MOTION.3, TEMPERATURE.1, X1.1 (3V3)

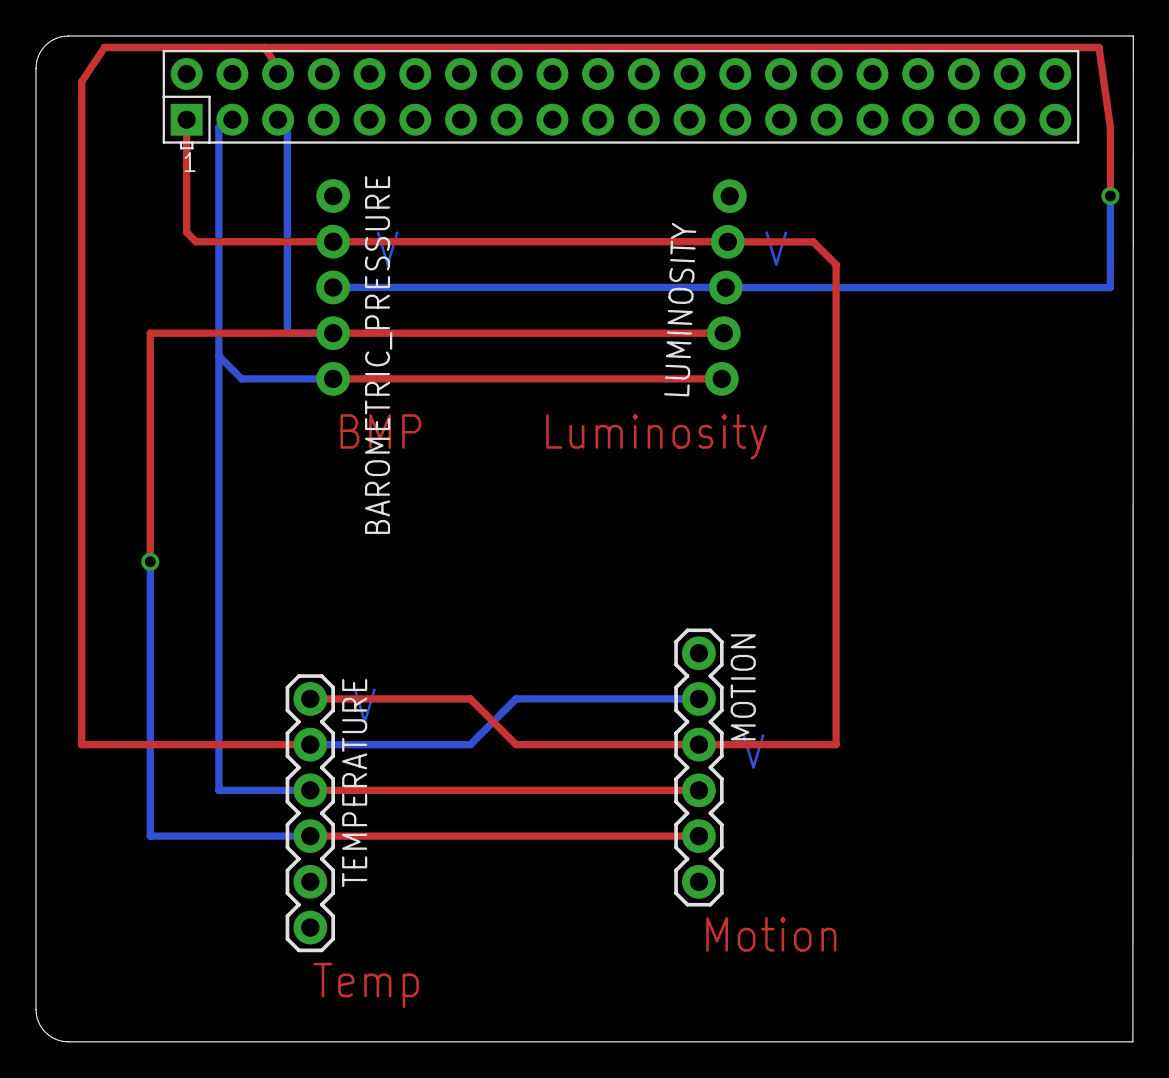
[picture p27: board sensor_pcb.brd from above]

Board: 2 copper layers, 61.0 x 55.9 mm, 5 parts (0 on the bottom side), 4 nets.

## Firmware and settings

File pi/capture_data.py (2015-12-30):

import ConfigParser, datetime, os, psycopg2, secrets, smbus, time
import Adafruit_BMP.BMP085 as BMP085


bmp_sensor = None
bus = smbus.SMBus(1)
sensor_cfg = ConfigParser.ConfigParser()


def init_db():
    conn = psycopg2.connect(user="admin", password="XXX", host="aws-us-east-1-portal.8.dblayer.com", port="10013", database="compose")
#    server['smart_building_development']
    return conn


def init_sensors():

    for sensor_name in sensor_cfg.sections():
        if sensor_cfg.has_option(sensor_name, 'power_signal_required'):
            address = int(sensor_cfg.get(sensor_name, 'address'), 16)
            ctrl_reg_address = int(sensor_cfg.get(sensor_name, 'ctrl_reg'), 16)
            ctrl_reg_power_mask = int(sensor_cfg.get(sensor_name, 'ctrl_power_on'), 16)
            bus.write_byte_data(address, ctrl_reg_address, ctrl_reg_power_mask)

        if sensor_cfg.has_option(sensor_name, 'custom_init_func'):
            init_func = sensor_cfg.get(sensor_name, 'custom_init_func')
            globals()[init_func](sensor_name)


def init_bp(sensor_name):
    global bmp_sensor
    bmp_sensor = BMP085.BMP085()


def init_gest(sensor_name):
    address = int(sensor_cfg.get(sensor_name, 'address'), 16)
    gesture_ctrl_reg_address = int("0xAB", 16)
    gesture_mode_mask = int("0x01", 16)
    bus.write_byte_data(address, gesture_ctrl_reg_address, gesture_mode_mask)

    gesture_conf2_reg_address = int("0xA3", 16)
    gesture_conf2_mask = int("0x07", 16)
    bus.write_byte_data(address, gesture_conf2_reg_address, gesture_conf2_mask)

    gesture_dim_address = int("0xAA", 16)
    gesture_dim_mask = int("0x02", 16)
    bus.write_byte_data(address, gesture_dim_address, gesture_dim_mask)

    gesture_exit_thresh_address = int("0xA1", 16)
    gesture_exit_thresh_mask = int("0x00", 16)
    bus.write_byte_data(address, gesture_exit_thresh_address, gesture_exit_thresh_mask)

#    gesture_ctrl_reg2_address = int("0x8F", 16)
#    gesture_ctrl_reg2_mask = int("0xC0", 16)
#    bus.write_byte_data(address, gesture_ctrl_reg2_address, gesture_ctrl_reg2_mask)

    gesture_conf_reg_address = int("0x90", 16)
    gesture_conf_reg_mask = int("0x30", 16)
    bus.write_byte_data(address, gesture_conf_reg_address, gesture_conf_reg_mask)

    gesture_enable_address = int("0x80", 16)
    gesture_enable_mask = int("0x45", 16)
    bus.write_byte_data(address, gesture_enable_address, gesture_enable_mask)


def capture_data(conn):

    for sensor_name in sensor_cfg.sections():
        sensor_id = sensor_cfg.get(sensor_name, 'pk')
        data = None
        if sensor_cfg.has_option(sensor_name, 'custom_capture_func'):
            capture_func = sensor_cfg.get(sensor_name, 'custom_capture_func')
            data = globals()[capture_func](sensor_name)
        else:
            address = int(sensor_cfg.get(sensor_name, 'address'), 16)
            data_reg_address = 0x00
            if sensor_cfg.has_option(sensor_name, 'data_reg'):
                data_reg_address = int(sensor_cfg.get(sensor_name, 'data_reg'), 16)
            data = bus.read_byte_data(address, data_reg_address)

        if sensor_cfg.has_option(sensor_name, 'callback'):
            func_name = sensor_cfg.get(sensor_name, 'callback')
            data = globals()[func_name](data)

        cur = conn.cursor()
        cur.execute("INSERT INTO data_points (timestamp, sensor_id, data) VALUES (%s, %s, %s)", (datetime.datetime.now(), sensor_id, data))
        conn.commit()
        print("{}: {}".format(sensor_name, data))


def capture_bp(sensor_name):
    return float(bmp_sensor.read_pressure())


def capture_gest(sensor_name):
    address = int(sensor_cfg.get(sensor_name, 'address'), 16)
    up_data_reg_address = int("0xFC", 16)
    down_data_reg_address = int("0xFD", 16)
    left_data_reg_address = int("0xFE", 16)
    right_data_reg_address = int("0xFF", 16)
    valid_data_reg_address = int("0xAE", 16)

    left_count = 0
    right_count = 0

    valid_data_count = bus.read_byte_data(address, valid_data_reg_address)
    for i in range(valid_data_count):
        bus.read_byte_data(address, up_data_reg_address)
        bus.read_byte_data(address, down_data_reg_address)

        left_data = bus.read_byte_data(address, left_data_reg_address)
        left_count = left_count + left_data

        right_data = bus.read_byte_data(address, right_data_reg_address)
        right_count = right_count + right_data

    return left_count - right_count


def count_people(sensor_name):

    if os.path.isfile("count.txt"):
        f = open("count.txt", "r")
        line = f.readline()
        f.close()
        if line != "":
            return float(line)
    return 0.0


def convert_temp(cels):

    return float((float(cels) * float(9.0 / 5.0)) + 32.0)


def convert_lux(second_byte):

    first_byte = bus.read_byte_data(0x29, 0x8D)
    return ((first_byte << 8) + second_byte) / 1000.0


def convert_bp(pascals):

    return pascals / 1000.0


if __name__ == '__main__':
    conn = init_db()

    sensor_cfg.read('/home/pi/scm-scripts/conf/sensors.ini')
    init_sensors()

    while True:
        capture_data(conn)
        time.sleep(2)

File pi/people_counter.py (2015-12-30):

# import the necessary packages
import datetime
import imutils
import time
import cv2

from picamera import PiCamera
from picamera.array import PiRGBArray

SENSITIVITY = 40 # 0-255, lower==more sensitive
state = ''
people = 0

# if the video argument is None, then we are reading from webcam
camera = PiCamera()
camera.resolution = (640, 480)
camera.framerate = 32
rawCapture = PiRGBArray(camera, size=(640,480))
time.sleep(1.0)

# initialize the first frame in the video stream
firstFrame = None

# loop over the frames of the video
for rawCapture in camera.capture_continuous(rawCapture, format="bgr", use_video_port=True):
    # grab the current frame and initialize the occupied/unoccupied
    # text
    text = "Unoccupied"

    frame = rawCapture.array
    rawCapture.truncate(0)

    # resize the frame, convert it to grayscale, and blur it
    gray = cv2.cvtColor(frame, cv2.COLOR_BGR2GRAY)
    gray = cv2.GaussianBlur(gray, (21, 21), 0)

    # if the first frame is None, initialize it
    if firstFrame is None:
        firstFrame = gray
        continue

    # compute the absolute difference between the current frame and
    # first frame
    frameDelta = cv2.absdiff(firstFrame, gray)
    thresh = cv2.threshold(frameDelta, SENSITIVITY, 255, cv2.THRESH_BINARY)[1]

    # dilate the thresholded image to fill in holes, then find contours
    # on thresholded image
    thresh = cv2.dilate(thresh, None, iterations=2)
    (cnts, _) = cv2.findContours(thresh.copy(), cv2.RETR_EXTERNAL,
                                 cv2.CHAIN_APPROX_SIMPLE)

    if len(cnts) == 0:
        state = ''
    # loop over the contours
    max_area = 1500
    for c in cnts:
        # if the contour is too small, ignore it
        if cv2.contourArea(c) < max_area:
            continue
        max_area = cv2.contourArea(c)

        # compute the bounding box for the contour, draw it on the frame,
        # and update the text
        (x, y, w, h) = cv2.boundingRect(c)
        frame_h, frame_w, frame_ch = frame.shape

        if (x+w < frame_w/4):
            cv2.rectangle(frame, (x, y), (x + w, y + h), (0, 255, 0), 2)
            text = "Left"
            if (state == 'r'):
                people -= 1
                print "People: ", people
                f = open('count.txt', 'w')
                f.write(str(people))
                f.close()
                state = ''
                break
            else:
                state = 'l'
        elif (x > (frame_w - frame_w/4)):
            cv2.rectangle(frame, (x, y), (x + w, y + h), (0, 255, 0), 2)
            text = "Right"
            if (state == 'l'):
                people += 1
                print "People: ", people
                f = open('count.txt', 'w')
                f.write(str(people))
                f.close()
                state = ''
                break
            else:
                state = 'r'

    # draw the text and timestamp on the frame
    # cv2.putText(frame, "Room Status: {}".format(text), (10, 20),
    #            cv2.FONT_HERSHEY_SIMPLEX, 0.5, (0, 0, 255), 2)
    # cv2.putText(frame,
    #            datetime.datetime.now().strftime("%A %d %B %Y %I:%M:%S%p"),
    #            (10, frame.shape[0] - 10),
    #            cv2.FONT_HERSHEY_SIMPLEX, 0.35, (0, 0, 255), 1)

    # show the frame and record if the user presses a key
    # cv2.imshow("Debug Feed", frame)

    # if the `q` key is pressed, break from the lop
    key = cv2.waitKey(1) & 0xFF
    if key == ord("q"):
        break

# cleanup the camera and close any open windows
camera.release()
cv2.destroyAllWindows()

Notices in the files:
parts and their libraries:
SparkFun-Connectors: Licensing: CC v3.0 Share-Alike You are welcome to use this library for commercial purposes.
